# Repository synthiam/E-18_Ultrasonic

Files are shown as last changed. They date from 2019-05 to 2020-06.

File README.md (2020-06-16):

# E-18 Ultrasonic

**Project Status:** Ready to manufacture

If you are new to GitHub and would like to create a derivative of this project, please have a look at GitHub instructions to [fork a repo](https://help.github.com/en/articles/fork-a-repo)

## Description

Out of our passion to solve the issue of time waste in the robot creation process, ARC was born. The ARC software platform reduces the time it takes to get from idea to implementation. Since 2011 we have been listening to the challenges robot builders encounter and continue to provide them with an ever expanding toolbox of solutions. Join us on this journey!

We didn't stop at the software, we also made time saving hardware solutions. This Ultrasonic reference design is one of them. The values coming from this sensor can be used to determine real world distance, collision detection, or objects detected by simulated radar when combined with ARC. This unique design has an integrated 5V regulator and only uses 3 wires instead of 4. We want to share these files with you so you can create your own version for your community and customers to enjoy!

**Features:** 
- Only one Digital I/O pin required (+ 2 power pins)
- Programming header
- On-board 5V regulation for HC-SR04
- 5V tolerant I/O pins
- Red LED status indicator
- Multiple ARC skills available
- Voltage input requirement: 6-20VDC
- Current draw: 9mA
- Dimensions: 45.2(W) x 20.3(L) x 29.7(H) (mm)
- Weight: 11g

**Major components:** 
- PIC16F1704-I/ST PIC microcontroller (custom firmware provided)
- NCP1117ST50T3GOSCT 5V Regulator
- HC-SR04 Ultrasonic sensor

**Manufacturing notes:** 
1. Supplier: provides pre-built HC-SR04 Sensor
2. Supplier: programs custom firmware into the PIC16F1704-I/ST at their facility before sending to manufacturer
3. Manufacturer: Single side placement and soldering of SMT components
4. Manufacturer: Dual Side soldering of THT components

## Contents

[**Documentation:**](https://github.com/synthiam/E-18_Ultrasonic/tree/master/E-18%20Documentation) Schematic PDF, Datasheet PDF, BOM, Assembly Notes, Test Procedures

[**Hardware:**](https://github.com/synthiam/E-18_Ultrasonic/tree/master/E-18%20Hardware) Altium PCB design File, Altium SCH Design File, Gerbers

[**Firmware:**](https://github.com/synthiam/E-18_Ultrasonic/tree/master/E-18%20Firmware) Code, Compiled Hex

*Altium Libraries are also available <a href="https://github.com/synthiam/Synthiam_Altium_Librairies">here</a>*

## Photos

<p align="left">

</p>

## Roll Out Video

This Roll-out Video includes:

1. Feature set 
2. Hook-up guide 
3. Using ARC skills
4. Schematic overview
5. Bill of Materials (BOM) overview
6. Custom firmware location
7. Assembly instructions 

Link: https://youtu.be/U_xIYUk4qag



## ARC Skills

There are 3 ARC skills that are directly related to the Ultrasonic. The Ultrasonic Distance, Collision Detection, and Radar controls. Grab the values from each of these controls with the click of a mouse button or with code. 

Link: https://synthiam.com/Products/Controls/Ultrasonic-Distance



## Contact

For profit use of these files requires written consent. Contact partners@synthiam.com. For everyone else, party on!

Synthiam Website: https://synthiam.com

## License

This project is released under the following licenses:

**Hardware:** Creative Commons Plus Attribution-NonCommercial 4.0 International (CC+ BY-NC 4.0)

**Firmware:** Apache 2.0 + “Commons Clause” License Condition v1.0

Please see [LICENSE.md](https://github.com/synthiam/E-18_Ultrasonic/blob/master/LICENSE.md) for license details.



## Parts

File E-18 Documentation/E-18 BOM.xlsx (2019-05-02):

Qty | Description | Manufacturer Part No. | Alternative | Designator | Custom Information | Link
E-18 Ultrasonic
1 | 2 layer, Blue soldermask, White silkscreen, ENIG | Ultrasonic Adapter Board |  | PCB
1 | MicroChip PIC microcontroller | PIC16F1704-I/ST |  | U1 | Needs custom Firmware programmed into chip | https://www.digikey.ca/products/en?keywords=PIC16F1704-I%2FST
1 | Ultrasonic Sensor | HC-SR04 |  | P2 |  | http://www.chinalctech.com/cpzx/Programmer/Sensor_Module/243.html
1 | 5V Linear voltage regulator (1A) upto 18V | NCP1117ST50T3GOSCT |  | VR1 |  | https://www.digikey.ca/products/en?keywords=NCP1117ST50T3GOSCT
1 | 0.1uF 16V 0805 Ceramic Capacitor | CL21F104ZBCNNNC | C0805C104K5RAC | C3
2 | 10uF 25V 0805 Ceramic Capacitor | CL21A106KAFN3NE |  | C1, C2
1 | 680ohm 0805 Resistor | RR1220P-681-D | CRCW0805680RFKEA | R1
1 | 40-pin Black Male 0.1” pitch header | FIT0084-B | 00834 | P1, P4 | This header needs to be broken down into 1 x 3-pin and 1 x 1-pin | http://www.4uconnector.com/online/SearchPro.asp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
1 | Red 0805 LED | LH R974-LP-1 |  | PWR | Watch that this LED doesn't get installed backward | https://www.digikey.ca/product-detail/en/osram-opto-semiconductors-inc/LH-R974-LP-1/475-1415-1-ND/1802604

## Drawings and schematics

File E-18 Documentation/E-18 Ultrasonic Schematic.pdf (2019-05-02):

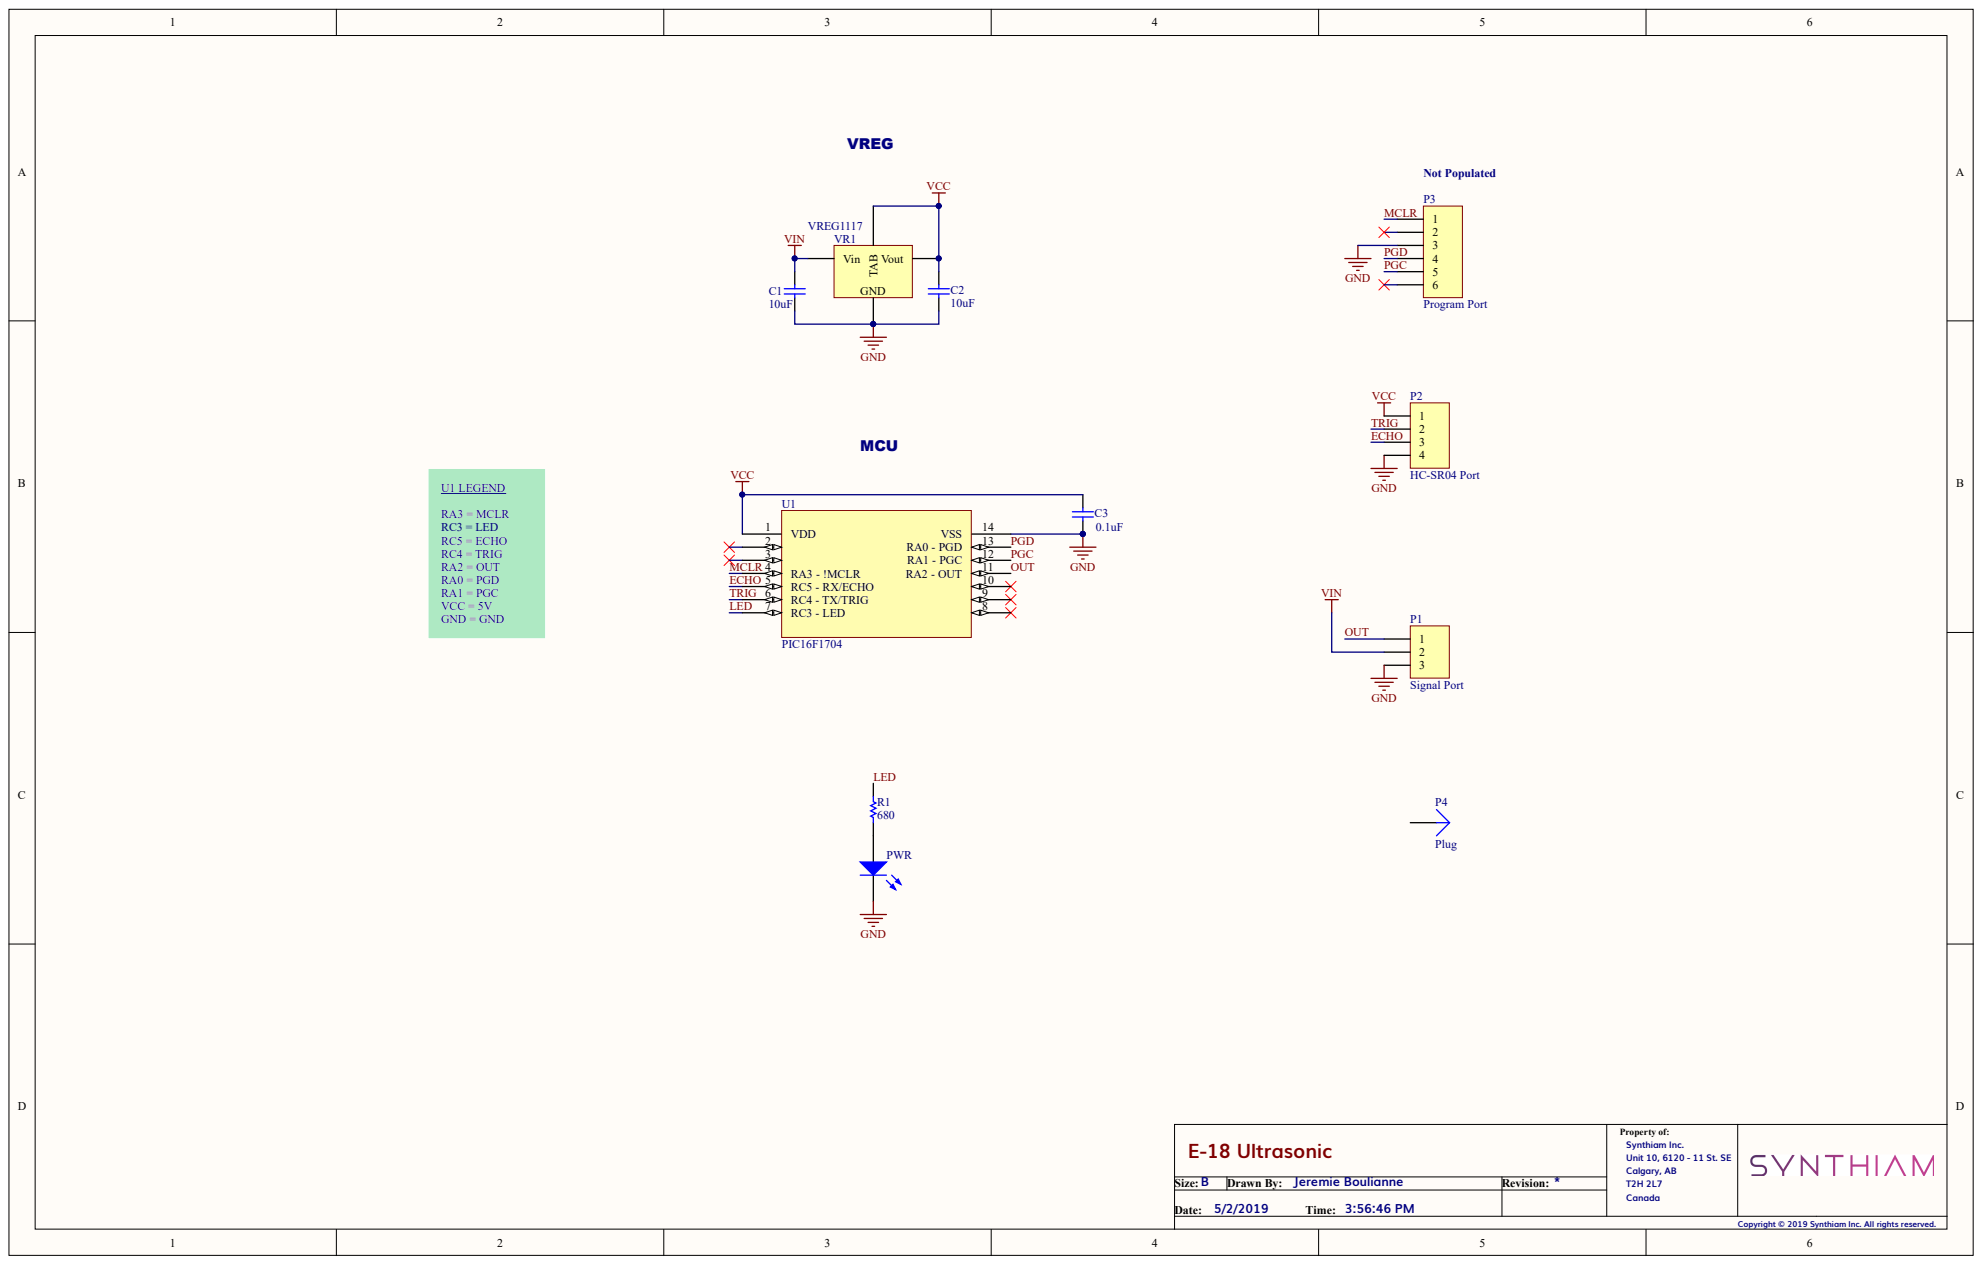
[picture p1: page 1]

E-18 Ultrasonic | Property of: Synthiam Inc. Unit 10, 6120 - 11 St. SE Calgary, AB T2H 2L7 Canada

B Size: | Jeremie Boulianne Drawn By: | * Revision:
5/2/2019 3:56:46 PM Date: Time:

Copyright © 2019 Synthiam Inc. All rights reserved.

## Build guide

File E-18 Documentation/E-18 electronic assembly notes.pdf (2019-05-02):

# Electronic Assembly Instructions

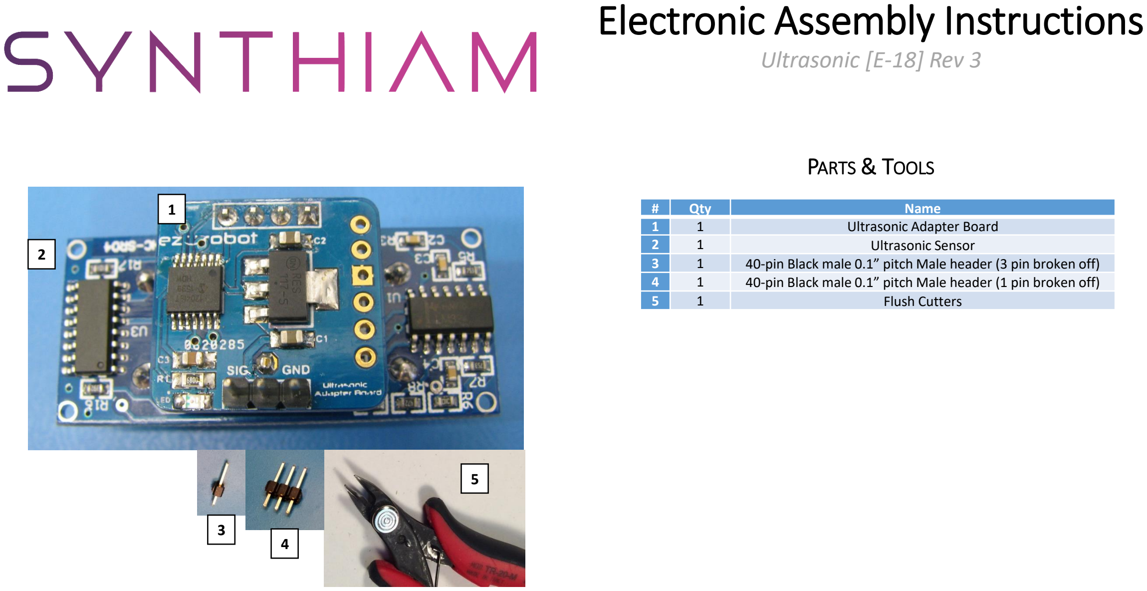
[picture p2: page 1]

# | Qty | Name

1 | 1 | Ultrasonic Adapter Board
2 | 1 | Ultrasonic Sensor
3 | 1 | 40-pin Black male 0.1” pitch Male header (3 pin broken off)
4 | 1 | 40-pin Black male 0.1” pitch Male header (1 pin broken off)
5 | 1 | Flush Cutters

Ultrasonic [E-18] Rev 3

PARTS & TOOLS

1

2

5

3
4

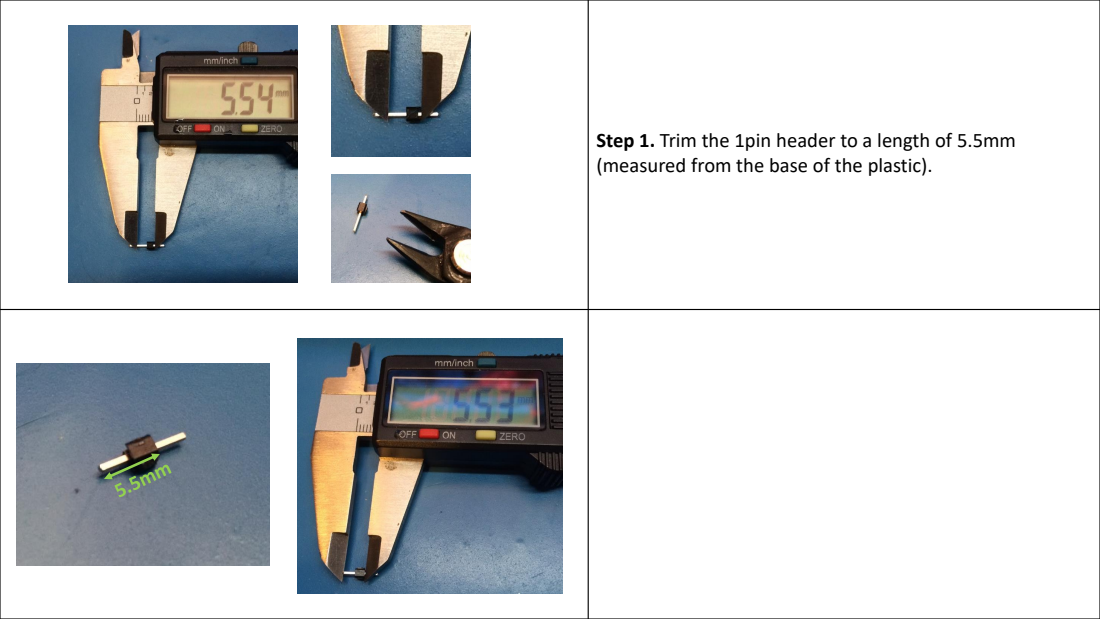
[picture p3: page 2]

Step 1. Trim the 1pin header to a length of 5.5mm
(measured from the base of the plastic).

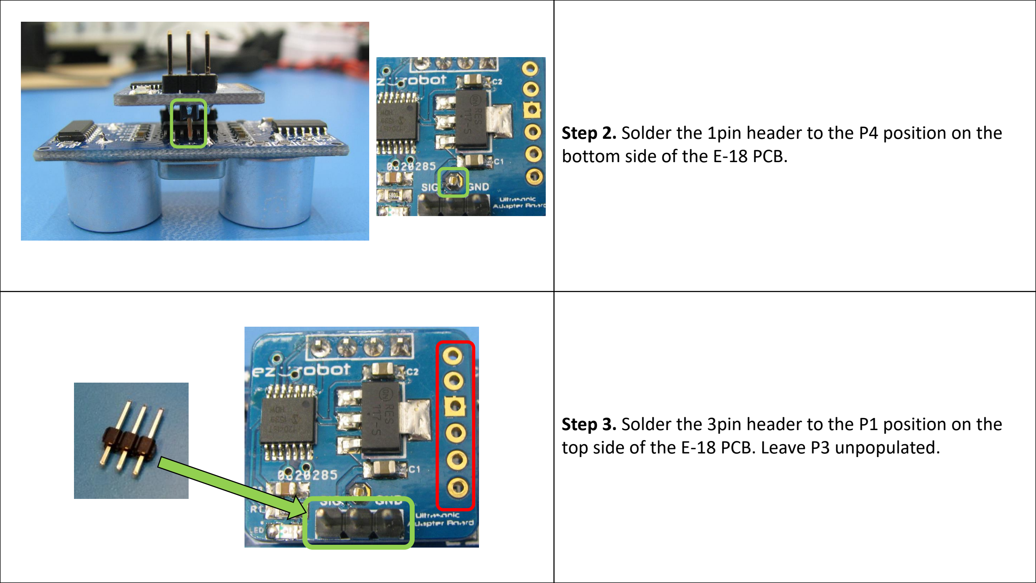
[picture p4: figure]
bottom side of the E-18 PCB.

Step 2. Solder the 1pin header to the P4 position on the
Step 3. Solder the 3pin header to the P1 position on the top side of the E-18 PCB. Leave P3 unpopulated.

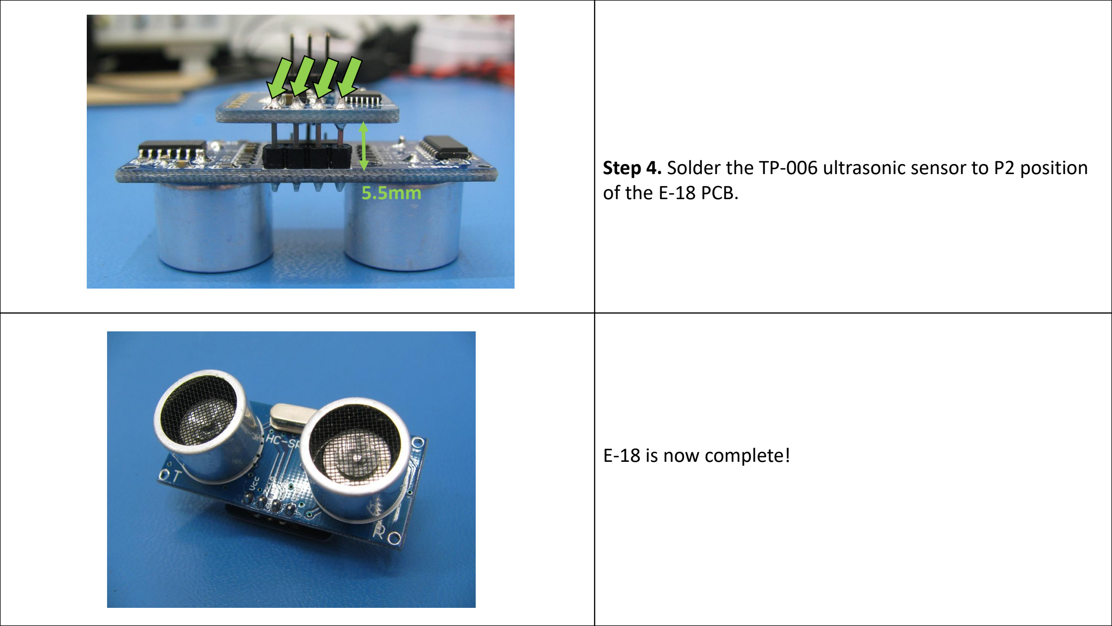
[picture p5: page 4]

Step 4. Solder the TP-006 ultrasonic sensor to P2 position of the E-18 PCB.

E-18 is now complete!

5.5mm

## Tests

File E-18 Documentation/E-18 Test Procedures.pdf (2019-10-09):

# E-18 Test Procedures

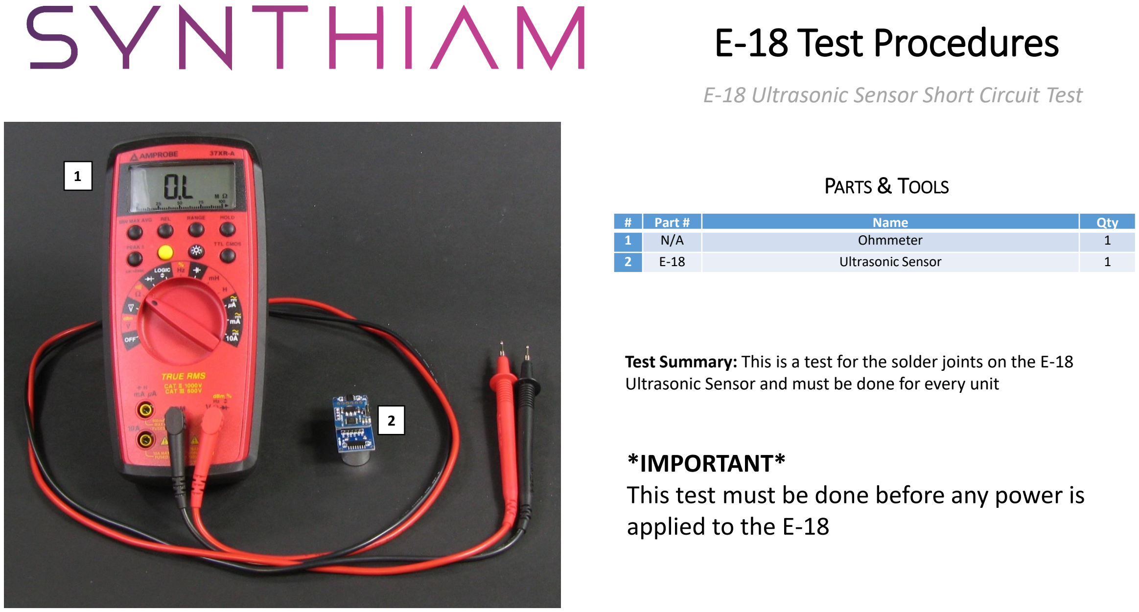
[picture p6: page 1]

# | Part # | Name | Qty

1 | N/A | Ohmmeter | 1
2 | E-18 | Ultrasonic Sensor | 1

E-18 Ultrasonic Sensor Short Circuit Test

PARTS & TOOLS

Test Summary: This is a test for the solder joints on the E-18 Ultrasonic Sensor and must be done for every unit

*IMPORTANT*
This test must be done before any power is applied to the E-18

1

2

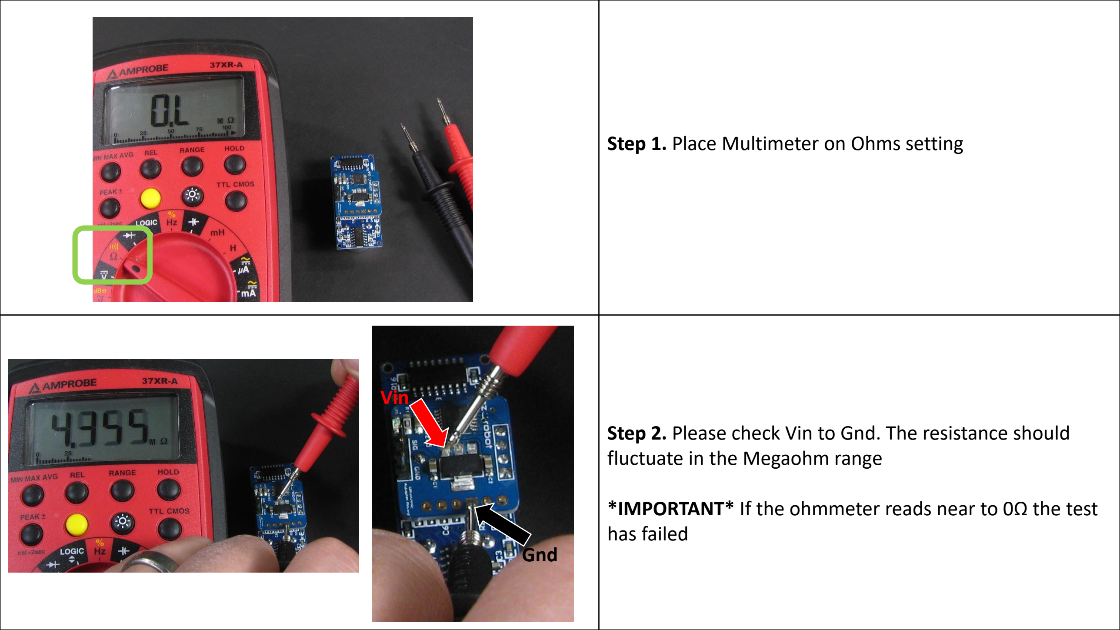
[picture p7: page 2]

Step 1. Place Multimeter on Ohms setting
Step 2. Please check Vin to Gnd. The resistance should fluctuate in the Megaohm range

*IMPORTANT* If the ohmmeter reads near to 0Ω the test has failed

Vin

Gnd

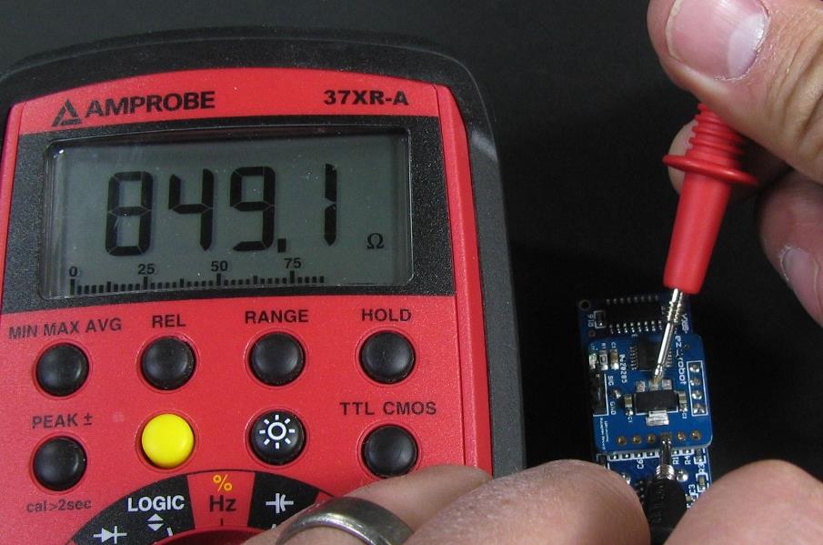
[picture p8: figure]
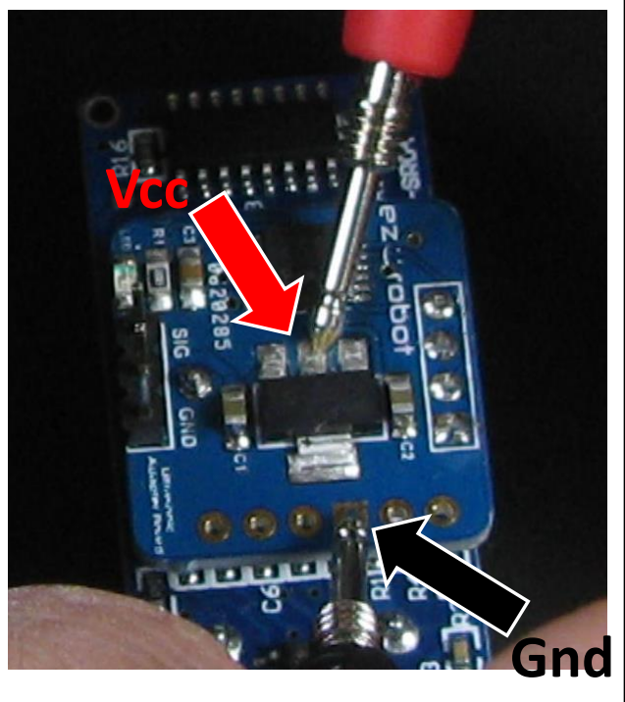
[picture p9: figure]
Vcc; Gnd

Step 3. Please check Vcc to Gnd. The resistance should be in the 800 ohm range. The E-18 Short Circuit Test is now complete

*IMPORTANT* If the ohmmeter reads near to 0Ω the test has failed

# E-18 Test Procedures

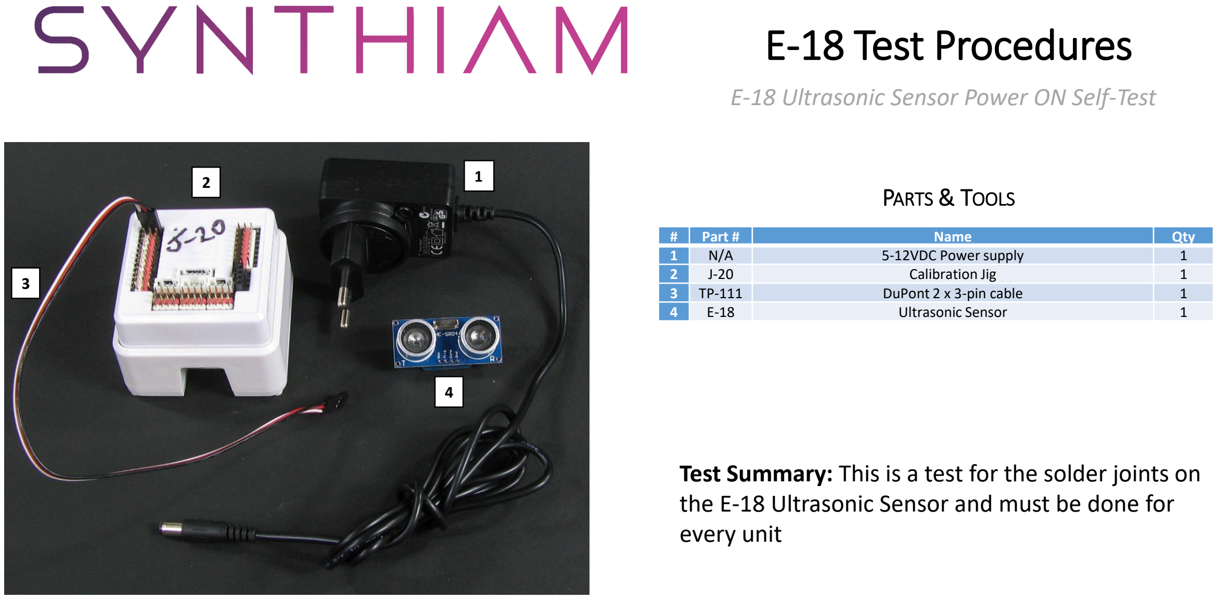
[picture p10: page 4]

# | Part # | Name | Qty

1 | N/A | 5-12VDC Power supply | 1
2 | J-20 | Calibration Jig | 1
3 | TP-111 | DuPont 2 x 3-pin cable | 1
4 | E-18 | Ultrasonic Sensor | 1

E-18 Ultrasonic Sensor Power ON Self-Test

PARTS & TOOLS

1
2

3

4

Test Summary: This is a test for the solder joints on the E-18 Ultrasonic Sensor and must be done for every unit

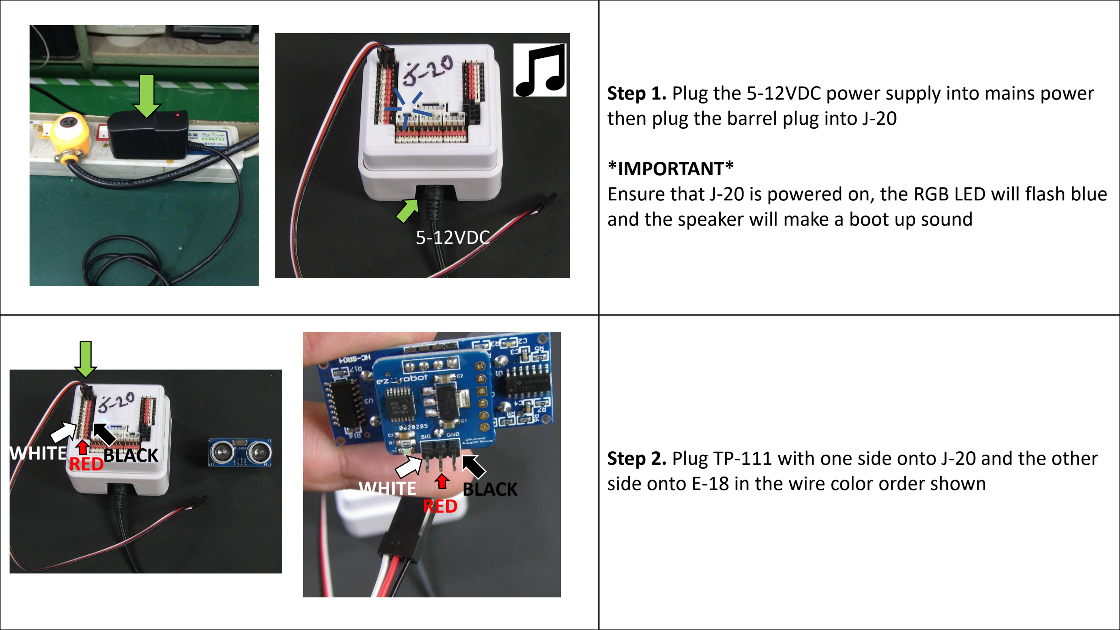
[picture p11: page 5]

Step 1. Plug the 5-12VDC power supply into mains power then plug the barrel plug into J-20

*IMPORTANT*
Ensure that J-20 is powered on, the RGB LED will flash blue and the speaker will make a boot up sound
Step 2. Plug TP-111 with one side onto J-20 and the other side onto E-18 in the wire color order shown

5-12VDC

WHITE
RED

BLACK

WHITEREDBLACK

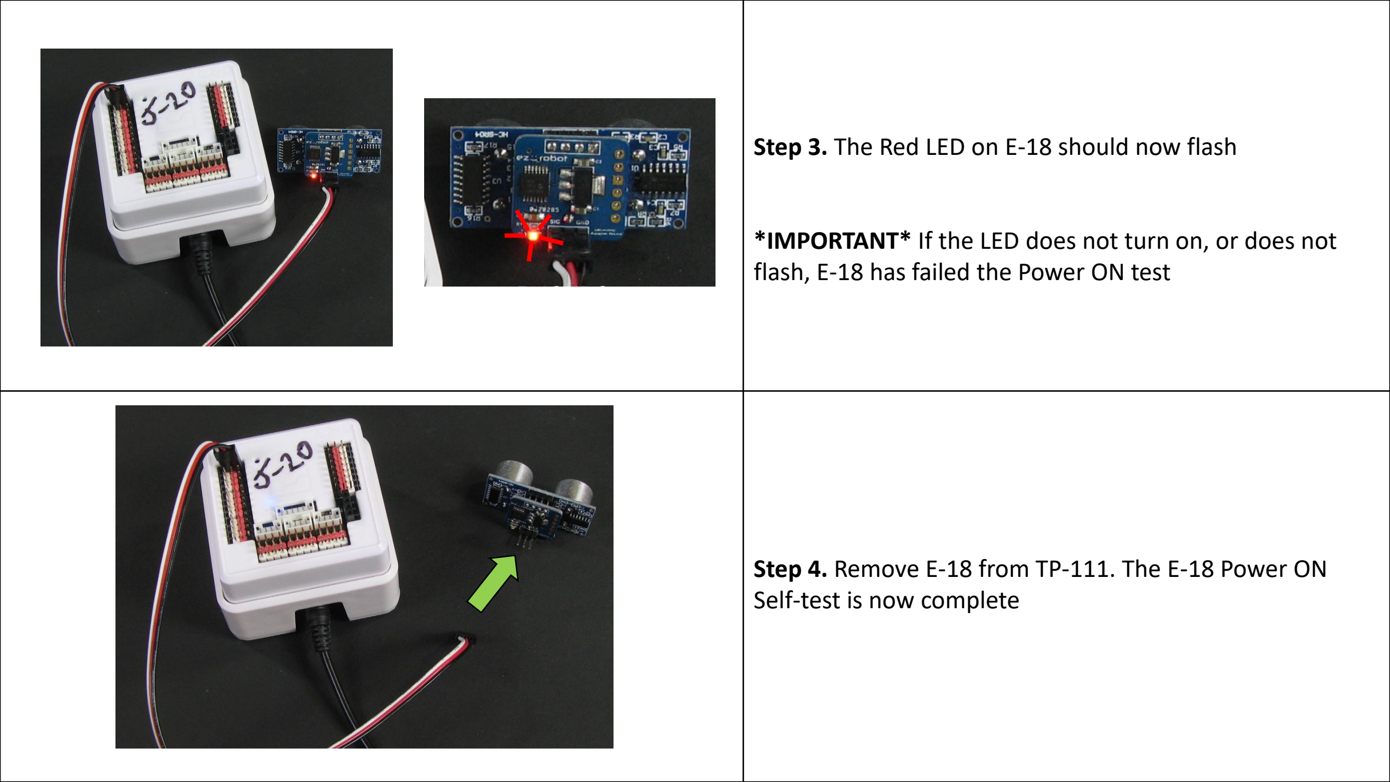
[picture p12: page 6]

Step 3. The Red LED on E-18 should now flash

*IMPORTANT* If the LED does not turn on, or does not flash, E-18 has failed the Power ON test

Step 4. Remove E-18 from TP-111. The E-18 Power ON Self-test is now complete

5-12VDC

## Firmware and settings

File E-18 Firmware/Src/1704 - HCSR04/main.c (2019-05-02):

#include <main.h>

void main() {

  delay_ms(250);

  output_drive(PORT_LED);
  output_low(PORT_LED);
  
  output_drive(PORT_TRIGGER);
  output_low(PORT_TRIGGER);

  output_float(PORT_ECHO);  
  
  while(true) {
    
    unsigned int16 cnt  = 0;
    unsigned int16 cnt2 = 0;
        
    // wait for 10 us trigger from client
    // Universal is INPUT
    // ---------------------------------------------------------------------------------------------------------------
    
    output_float(PORT_UNIVERSAL);
    
    // wait for client signal to go high
    while (!input(PORT_UNIVERSAL));
    output_high(PORT_TRIGGER);

    // wait for client signal to go low
    while (input(PORT_UNIVERSAL));
    output_low(PORT_TRIGGER);

    // Wait for the sensor to go high of returned value
    // Universal is OUTPUT
    // ---------------------------------------------------------------------------------------------------------------     

    output_high(PORT_LED);
   
    output_drive(PORT_UNIVERSAL);
    output_low(PORT_UNIVERSAL);

    delay_us(15);
    
    // loop until timeout for sensor to go high, which is the start the echo response
    do {

      // if the echo pin hasn't gone high in a certain amount of time, exit with a distance of 0
      if (cnt2 == HC_TIMEOUT_HIGH)
        break;
          
      cnt2++;
    } while (!input(PORT_ECHO));

    output_high(PORT_UNIVERSAL);

    // Wait for the sensor to go low which reflects the distance
    // ---------------------------------------------------------------------------------------------------------------     
    
    if (cnt2 == HC_TIMEOUT_HIGH) {
    
      // the sensor did not respond to our ping so we go high for an arbitrary amount of time to return a long distance
      delay_ms(1);
    } else {

      // the sensor responded to our ping so not let's wait until it goes low which reflects the distance or timeout
      do {
    
        // if the echo pin hasn't gone high in a certain amount of time, exit with a fake distance
        if (cnt == HC_TIMEOUT_LOW)
          break;
            
        cnt++;
      } while (input(PORT_ECHO));
    }
    
    output_low(PORT_UNIVERSAL);
    output_low(PORT_LED);    
  }
}
